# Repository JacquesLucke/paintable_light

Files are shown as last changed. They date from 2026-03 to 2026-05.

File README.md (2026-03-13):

# Paintable Light

Goals:
* I want to learn to make custom PCBs.
* Try to design something that children can solder, paint on and turn into a nice looking small light.

3D Render Top
3D Render Bottom
Bottom
Top

[Schematic](https://jacqueslucke.github.io/paintable_light/paintable_light_schematic.pdf)

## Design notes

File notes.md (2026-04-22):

* reverse polarity protection
* esd protection?
* usb-c connector
* battery connector 
* quick tester for backside
* slightly increase solder pad size for one side of an led

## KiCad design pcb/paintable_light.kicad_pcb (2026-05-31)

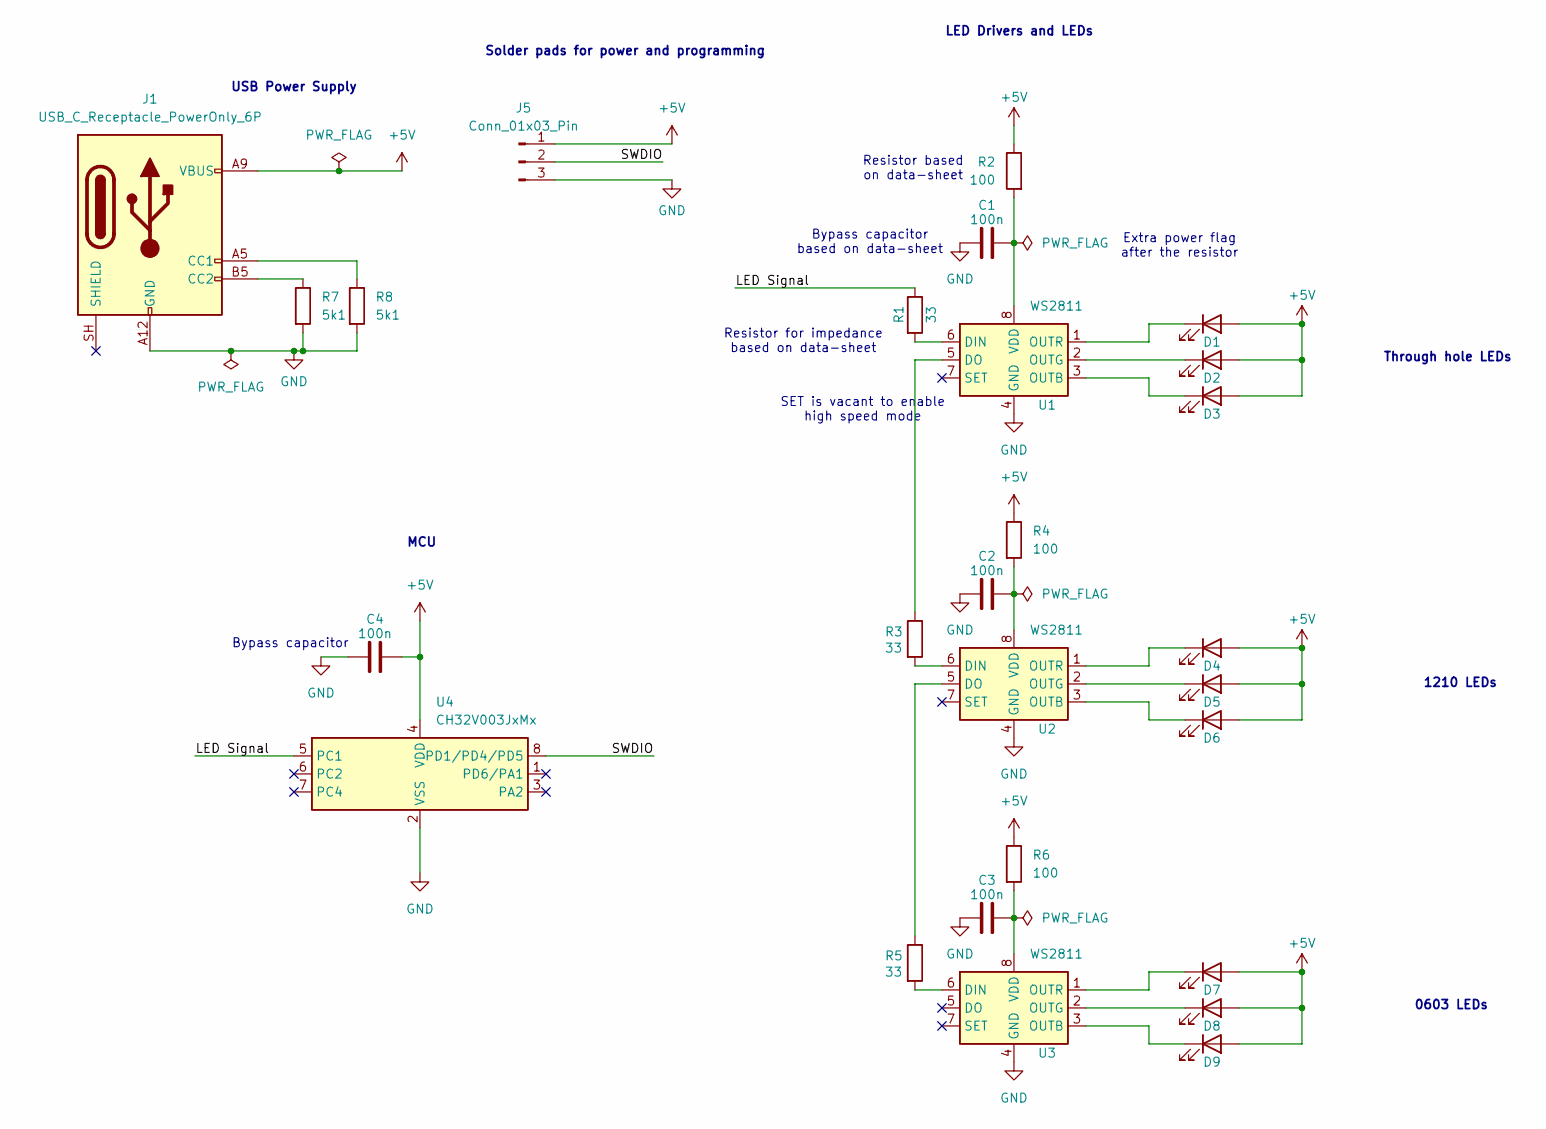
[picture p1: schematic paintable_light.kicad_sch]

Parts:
C1, C2, C3, C4: 100n; C_1206_3216Metric_Pad1.33x1.80mm_HandSolder
D1, D2, D3, D4, D5, D6, D7, D8, D9: LED; LED_1210_3225Metric_Pad1.42x2.65mm_HandSolder_front
J1: USB_C_Receptacle_PowerOnly_6P; usb_c_vertical_C5187465
J5: Conn_01x03_Pin; pin_header_flat_C41417360
R1, R3, R5: 33; R_1206_3216Metric_Pad1.30x1.75mm_HandSolder
R2, R4, R6: 100; R_1206_3216Metric_Pad1.30x1.75mm_HandSolder
R7, R8: 5k1; R_1206_3216Metric_Pad1.30x1.75mm_HandSolder
U1, U2, U3: WS2811; SOIC-8_3.9x4.9mm_P1.27mm
U4: CH32V003JxMx; JEITA_SOIC-8_3.9x4.9mm_P1.27mm

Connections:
+5V: C4.2, D1.2 (A), D2.2 (A), D3.2 (A), D4.2 (A), D5.2 (A), D6.2 (A), D7.2 (A), D8.2 (A), D9.2 (A), J1.A9 (VBUS), J1.B9 (VBUS), J5.1, R2.1, R4.1, R6.1, U4.4 (VDD)
/LED Signal: R1.1, U4.5 (PC1)
/SWDIO: J5.2, U4.8 (PD1/PD4/PD5)
GND: C1.1, C2.1, C3.1, C4.1, J1.A12 (GND), J1.B12 (GND), J5.3, R7.2, R8.2, U1.4 (GND), U2.4 (GND), U3.4 (GND), U4.2 (VSS)
unnamed: D1.1 (K), U1.1 (OUTR)
unnamed: D2.1 (K), U1.2 (OUTG)
unnamed: D3.1 (K), U1.3 (OUTB)
unnamed: D4.1 (K), U2.1 (OUTR)
unnamed: D5.1 (K), U2.2 (OUTG)
unnamed: D6.1 (K), U2.3 (OUTB)
unnamed: D7.1 (K), U3.1 (OUTR)
unnamed: D8.1 (K), U3.2 (OUTG)
unnamed: D9.1 (K), U3.3 (OUTB)
unnamed: J1.A5 (CC1), R8.1
unnamed: J1.B5 (CC2), R7.1
unnamed: R1.2, U1.6 (DIN)
unnamed: R3.1, U1.5 (DO)
unnamed: C1.2, R2.2, U1.8 (VDD)
unnamed: R3.2, U2.6 (DIN)
unnamed: R5.1, U2.5 (DO)
unnamed: C2.2, R4.2, U2.8 (VDD)
unnamed: R5.2, U3.6 (DIN)
unnamed: C3.2, R6.2, U3.8 (VDD)

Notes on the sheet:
Bypass capacitor based on data-sheet
Resistor based on data-sheet
SET is vacant to enable high speed mode
Bypass capacitor
Through hole LEDs
MCU
Resistor for impedance based on data-sheet
Extra power flag after the resistor
LED Drivers and LEDs
USB Power Supply
Solder pads for power and programming
1210 LEDs
0603 LEDs

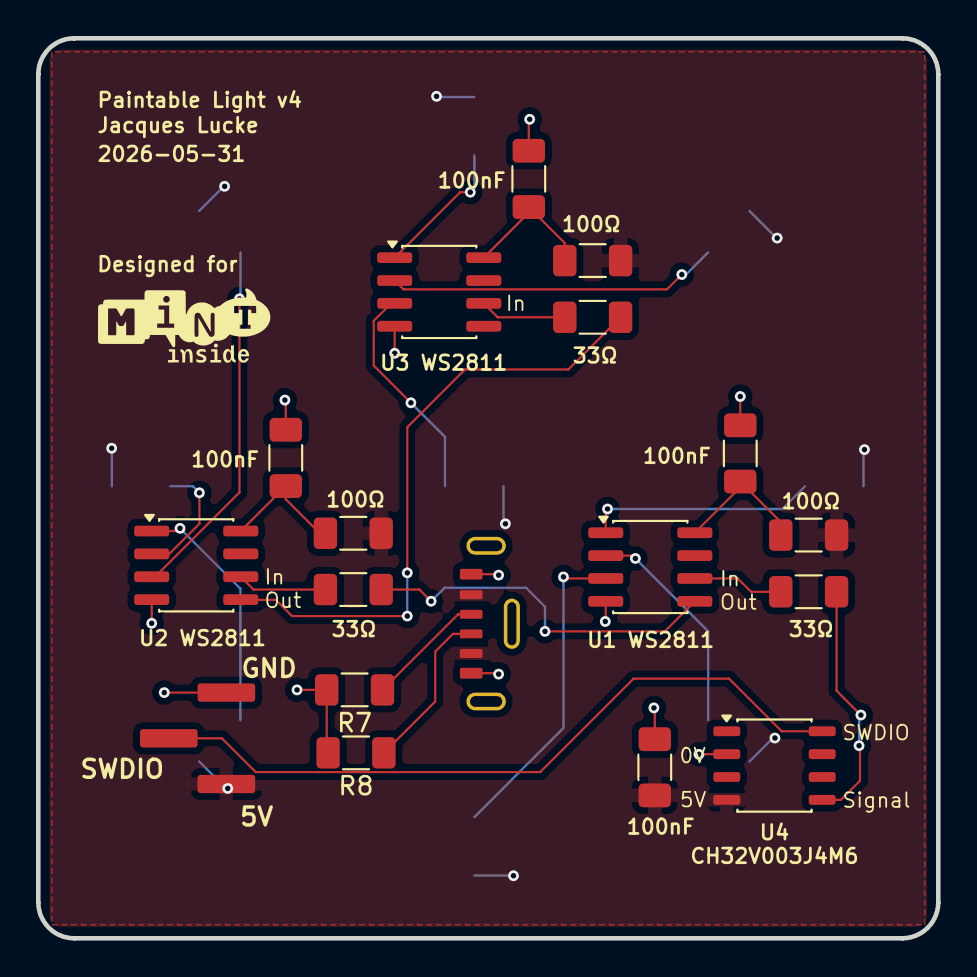
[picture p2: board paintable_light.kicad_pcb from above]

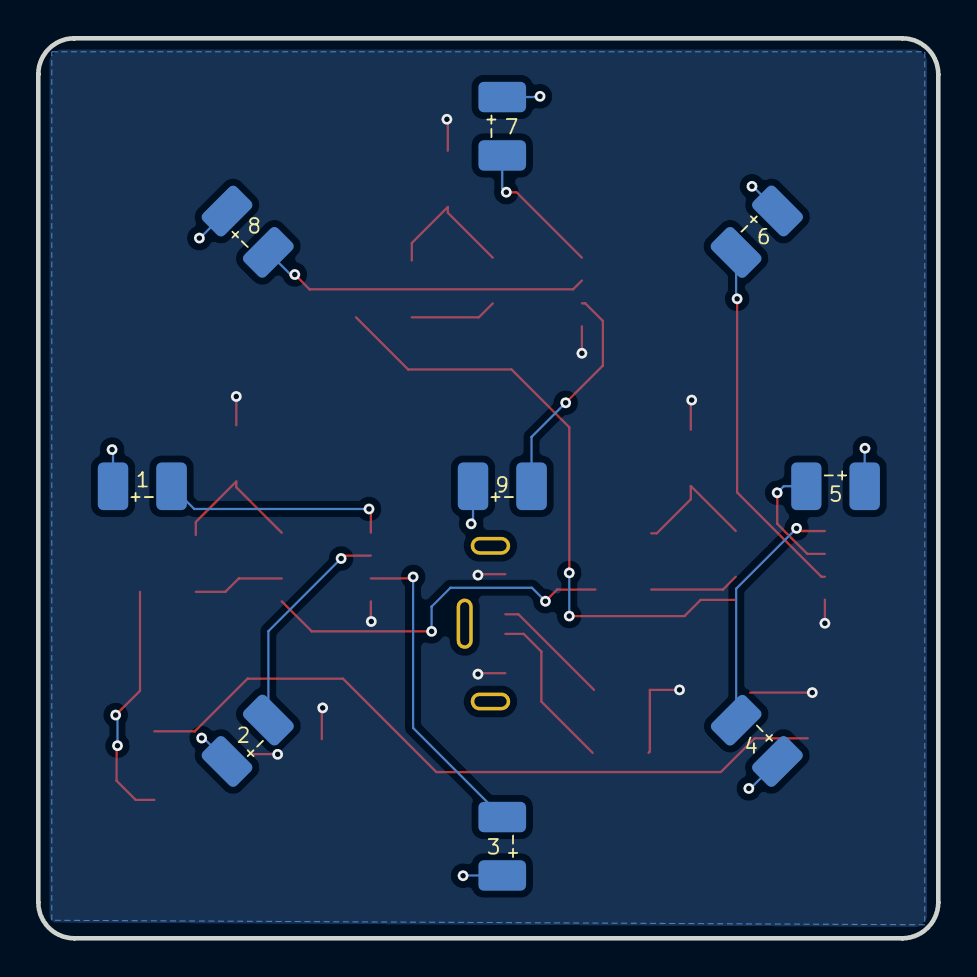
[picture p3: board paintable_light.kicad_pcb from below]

Board: 2 copper layers, 50.0 x 50.0 mm, 27 parts (9 on the bottom side), 23 nets.

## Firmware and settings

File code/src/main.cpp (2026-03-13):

#include <Arduino.h>
#include <array>

constexpr int led_pin = C1;

void setup() { pinMode(led_pin, OUTPUT); }

#define FORCE_INLINE __attribute__((always_inline)) inline

FORCE_INLINE void turn_on() { GPIOC->BSHR = GPIO_Pin_1; }

FORCE_INLINE void turn_off() { GPIOC->BCR = GPIO_Pin_1; }

FORCE_INLINE void tick() { __asm__ volatile("nop"); }

template <int N> FORCE_INLINE void ticks() {
  if constexpr (N > 0) {
    tick();
    ticks<N - 1>();
  }
}

constexpr int overhead = 6;

FORCE_INLINE void send_one() {
  turn_on();
  ticks<27>();
  turn_off();
  ticks<30 - overhead>();
}

FORCE_INLINE void send_zero() {
  turn_on();
  ticks<12>();
  turn_off();
  ticks<47 - overhead>();
}

FORCE_INLINE void send_byte(uint8_t byte) {
  for (int i = 0; i < 8; i++) {
    if (byte & 0x80) {
      send_one();
    } else {
      send_zero();
    }
    byte <<= 1;
  }
}

constexpr uint8_t smooth_brightnesses[34] = {
    1,   2,   3,   5,   7,   10,  13,  16,  20,  24,  29,  34,
    39,  45,  51,  58,  65,  72,  80,  88,  97,  106, 115, 125,
    135, 146, 157, 168, 180, 192, 205, 218, 231, 245};

static uint8_t get_brightness_at_time(int32_t time, int led_i) {
  int index = (time / 64 + (led_i * 50)) % (2 * sizeof(smooth_brightnesses));
  if (index >= int(sizeof(smooth_brightnesses))) {
    index = 2 * sizeof(smooth_brightnesses) - index - 1;
  }

  return smooth_brightnesses[index];
}

void loop() {
  while (true) {
    const int32_t now = millis();
    uint8_t values[9];
    for (int i = 0; i < 9; i++) {
      values[i] = get_brightness_at_time(now, i);
    }

    delay(50);

    __disable_irq();
    send_byte(values[0]);
    send_byte(values[1]);
    send_byte(values[2]);

    send_byte(values[3]);
    send_byte(values[4]);
    send_byte(values[5]);

    send_byte(values[6]);
    send_byte(values[7]);
    send_byte(values[8]);
    __enable_irq();
  }
}

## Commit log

2026-02-08 import jlcpcb settings
    [paintable_light.kicad_pcb]
2026-02-08 maybe finished schematic
    [paintable_light.kicad_sch]
2026-02-08 initial layout
    [paintable_light.kicad_pcb, paintable_light.kicad_sch]
2026-02-08 update layout
    [paintable_light.kicad_pcb]
2026-02-27 enable high speed
    [paintable_light.kicad_sch]
2026-02-27 initial new board layout
    [paintable_light.kicad_pcb, paintable_light.kicad_sch]
